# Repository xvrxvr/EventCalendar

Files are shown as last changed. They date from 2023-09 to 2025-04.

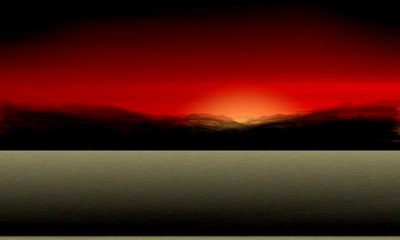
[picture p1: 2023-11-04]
soft/firmware/main/test_bg.jpg

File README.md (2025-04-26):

# EventCalendar
Event Calendar Project

This project is a custom hardware device (with an ESP32 microcontroller, an LCD, a fingerprint sensor, and a bunch of solenoids that are used as control locks for a set of small doors)
Each door closes a separate box with some kind of gift.
The user must solve some kind of puzzle to open the door.

## Project Contents

Directory Contents:

* 3D contains a 3D model for the panel around the LCD
* sch - Schematic. The PCB version is outdated at this point (some schematic changes were made after the PCB was provided). There are also 2 schematics:
  * **ev_cal** - The calendar itself
  * **vboost** - Voltage boost for the solenoids (it is connected instead of L1)
* soft - Software. 6 directories included:
  * expr_quest - Prototype (in Python) for benchmark testing
  * firmware - Firmware (VS Code + IDF plugin)
  * sg - Character generator scripts
  * tst - Hardware test (VS Code + IDF plugin)
  * bloader - OTA loader (OTA is also supported in the main software)
  * ext_logger - External logger client. The external logging system is currently under development. It allows forwarding all internal UART messages to a remote TCP server. This system (with OTA capability) allows creating and debugging new software versions without special software hardware.
* spice - Spice mode for the voltage amplifier

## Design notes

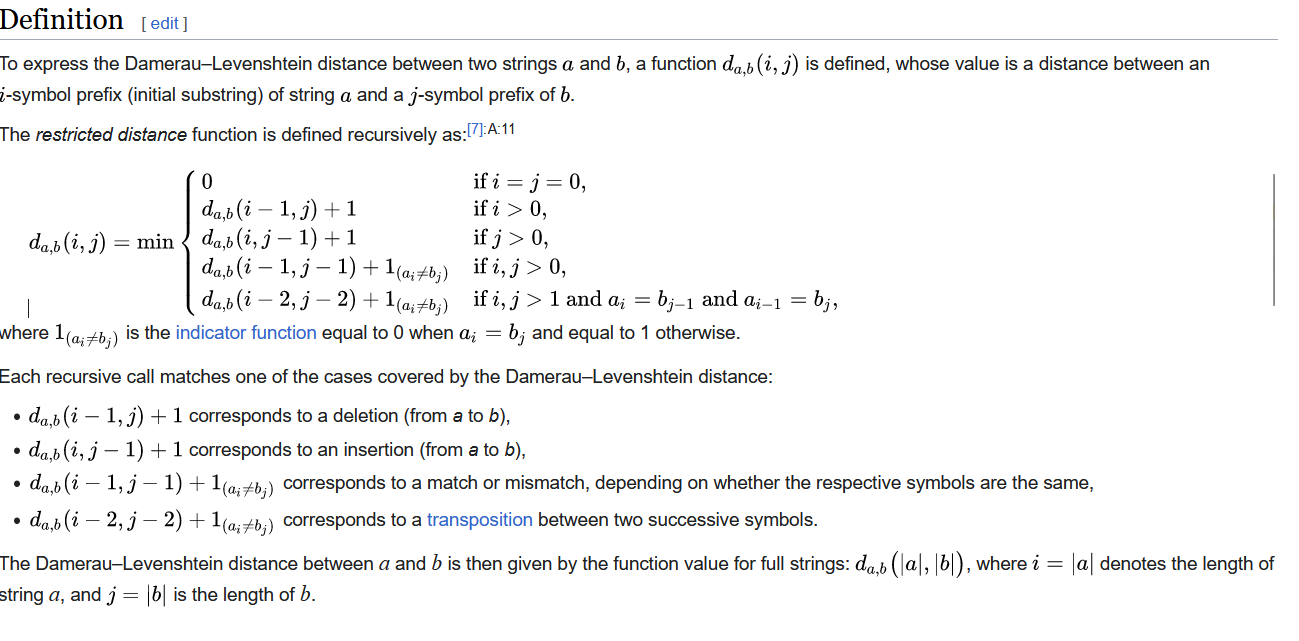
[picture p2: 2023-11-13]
text_draw/DV.png

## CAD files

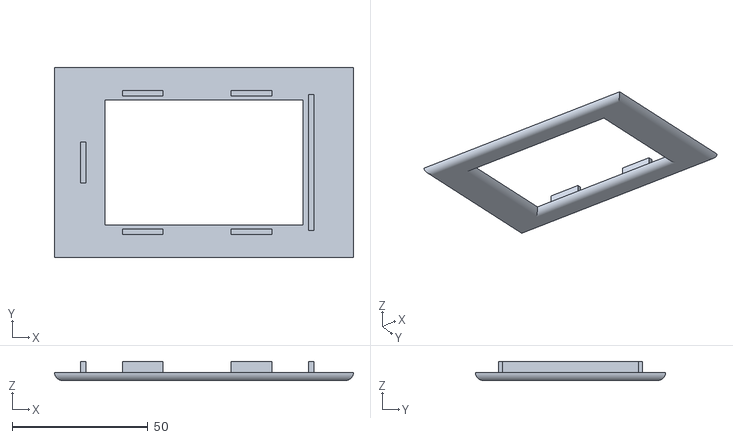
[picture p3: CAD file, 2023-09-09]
3D/lcd-panel-Body.stl
110.0 x 70.0 x 7.00

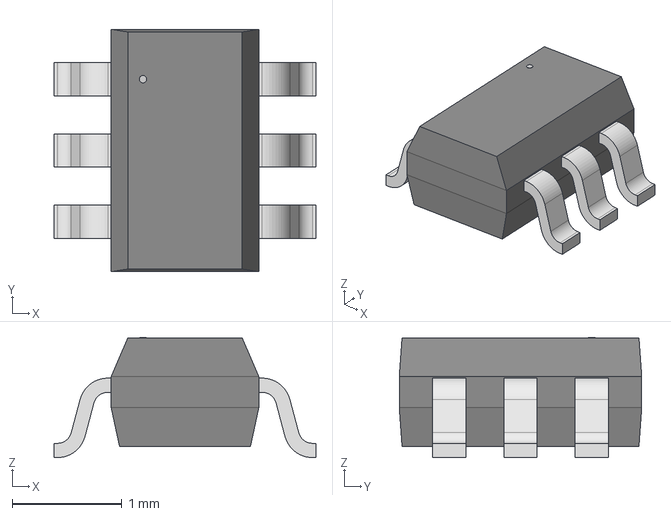
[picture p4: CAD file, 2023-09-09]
sch/ev_cal/KS_6_ADI.step
2.39 x 2.21 x 1.09 mm

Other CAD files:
3D/lcd-panel.FCStd

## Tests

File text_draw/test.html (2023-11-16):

? Run! | Text Visual Appearance setup

Box Model

| Vertical | Horizontal
Margin (0-63):
Padding (0-63):

Other Colors

Default Text color:
Panel color:

Answer Boxes (Selection) Setup

Center text vertically in Box:
Center text horizontally in Box:
Make Boxes equal vertically sized:
Make Boxes equal horizontally sized:

Box Sizing

Corner radius (0-63):
Border (0-63):
Shadow (0-63):

Age

Min: | | Max:

Options

Default char size: | | Input type:
Answer boxes layout:
Fuzzy compare distance (symbols or percent):
Word Wrap:

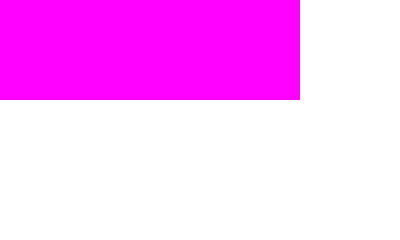
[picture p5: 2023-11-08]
test.png

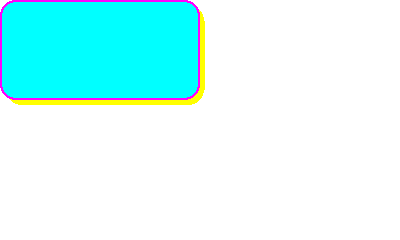
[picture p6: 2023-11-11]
test/test.png

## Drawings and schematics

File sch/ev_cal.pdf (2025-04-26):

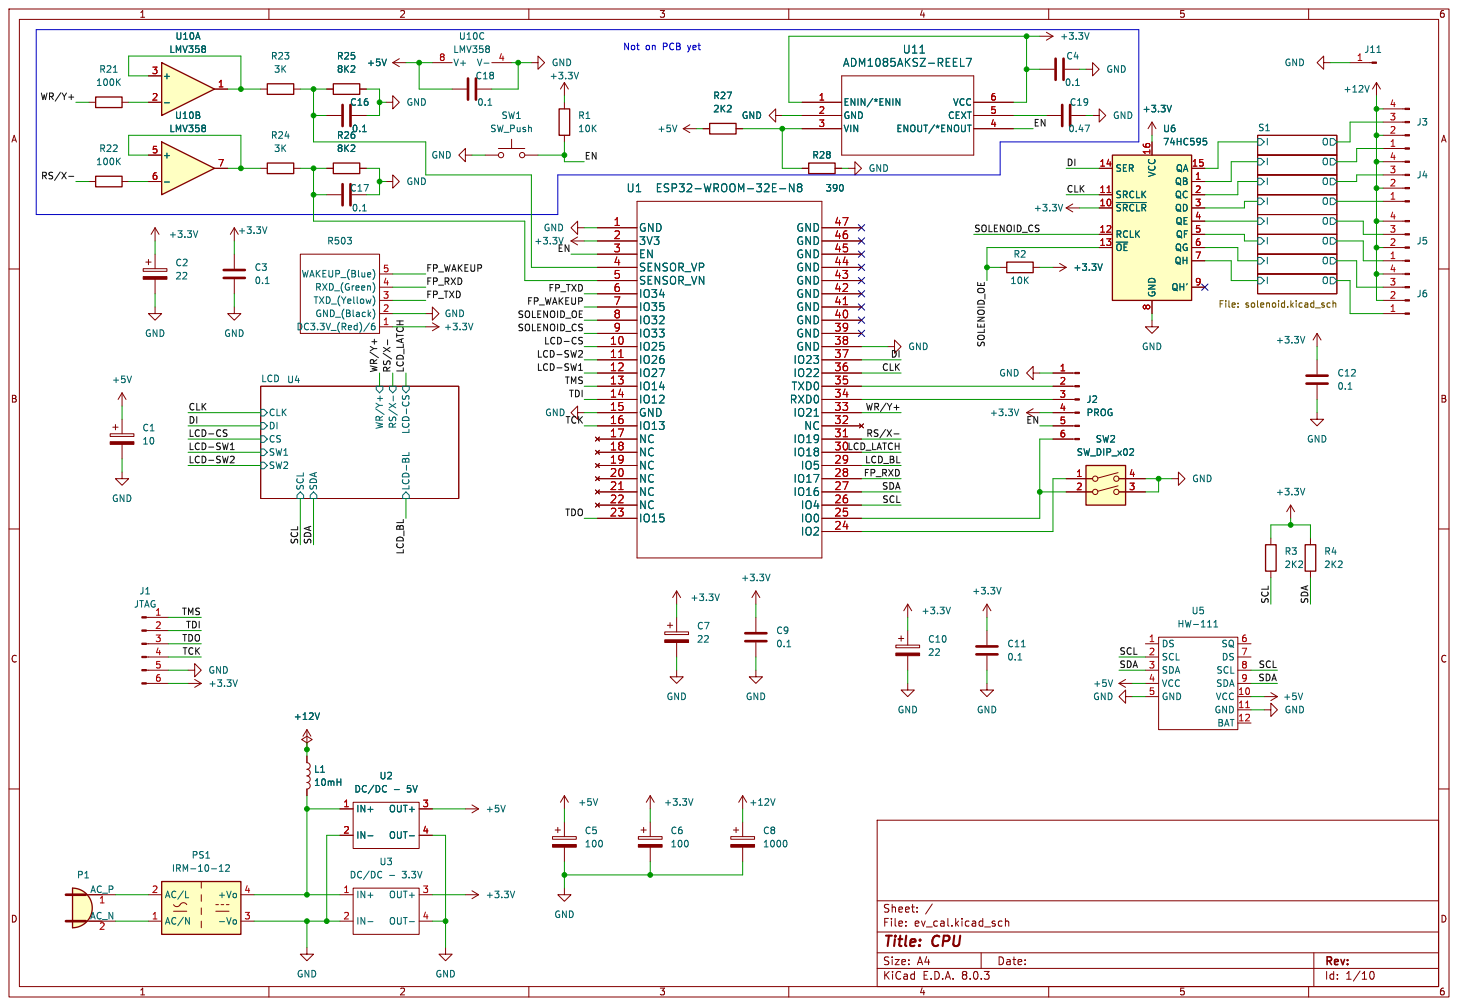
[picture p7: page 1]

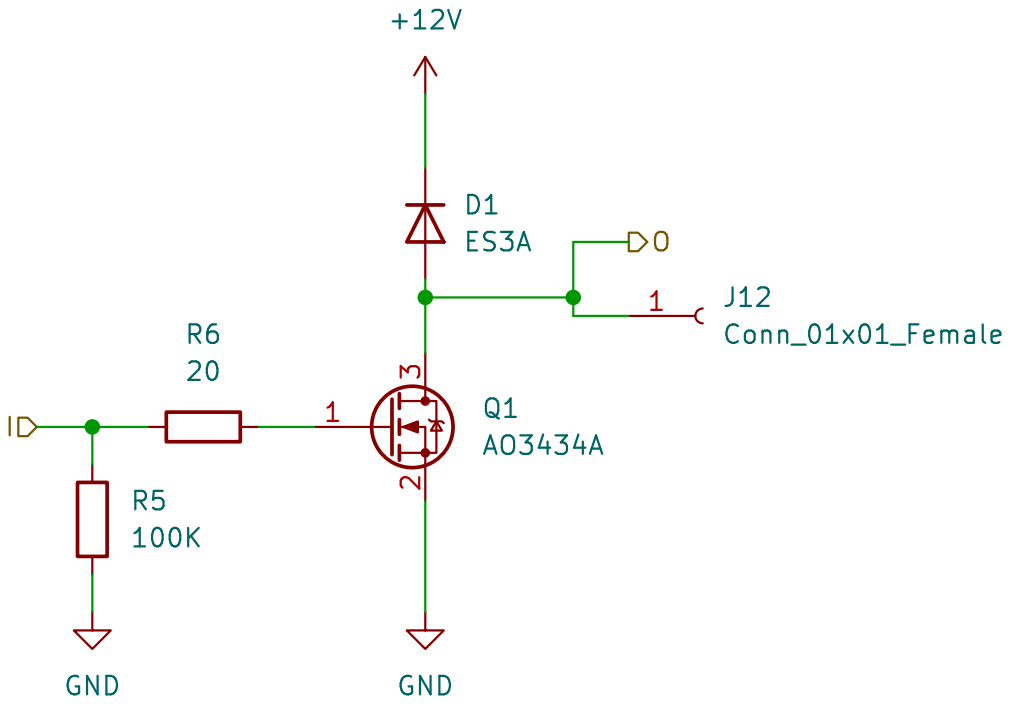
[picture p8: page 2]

Id: 2/10 Title: Solenoid Driver File: solenoid.kicad_sch Sheet: /S1/

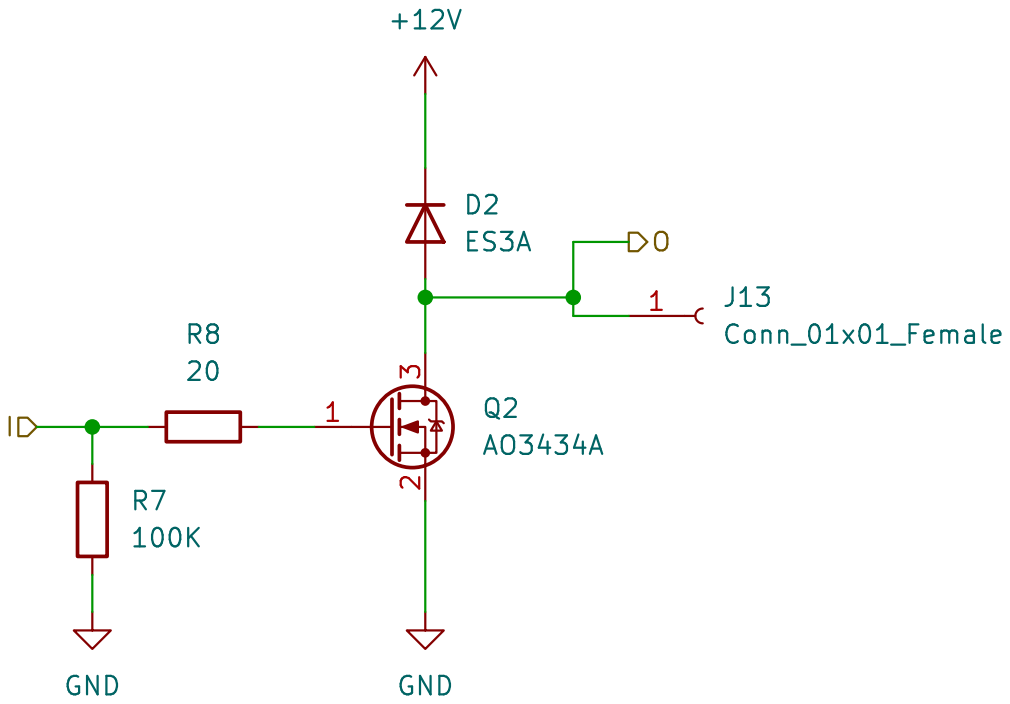
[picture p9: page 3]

Id: 3/10 Title: Solenoid Driver File: solenoid.kicad_sch Sheet: /S2/

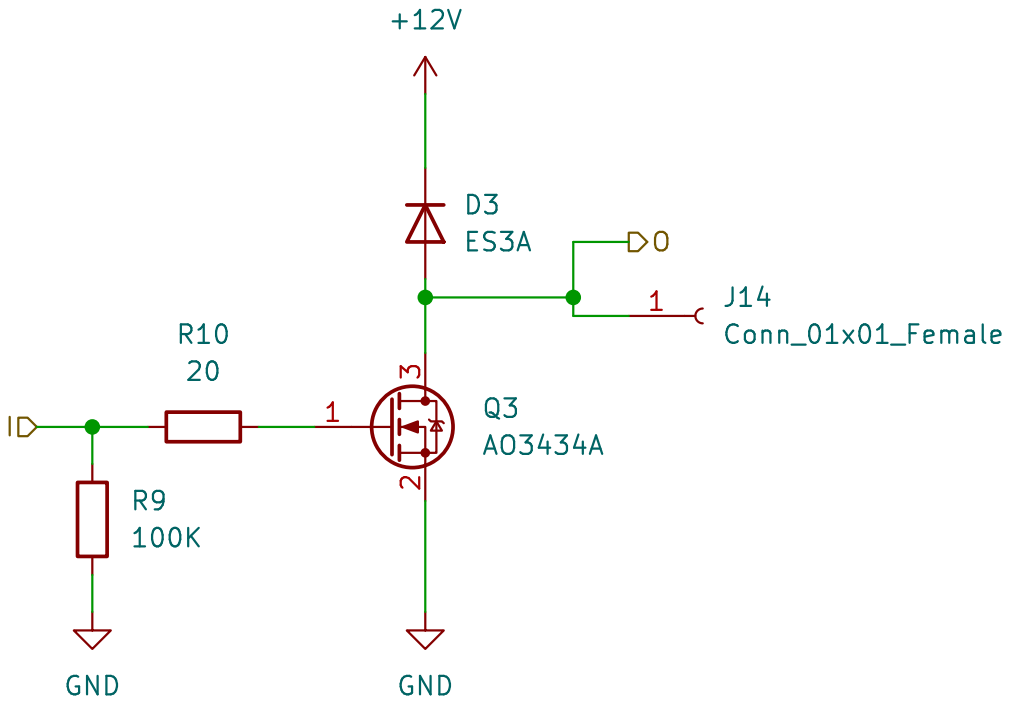
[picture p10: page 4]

Id: 4/10 Title: Solenoid Driver File: solenoid.kicad_sch Sheet: /S3/

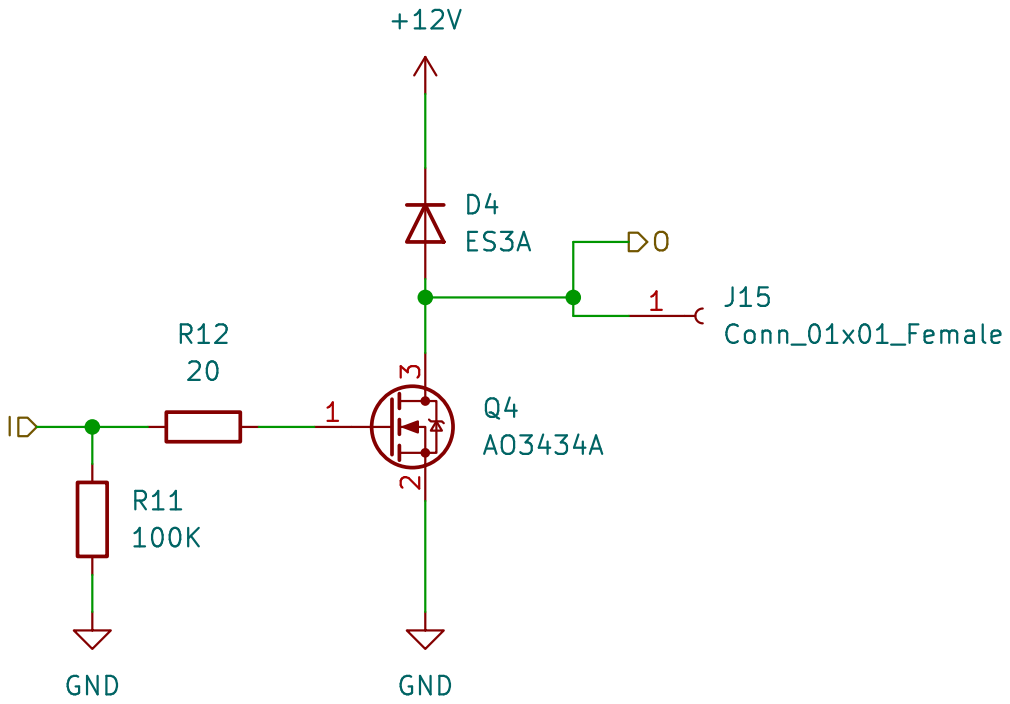
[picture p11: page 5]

Id: 5/10 Title: Solenoid Driver File: solenoid.kicad_sch Sheet: /S4/

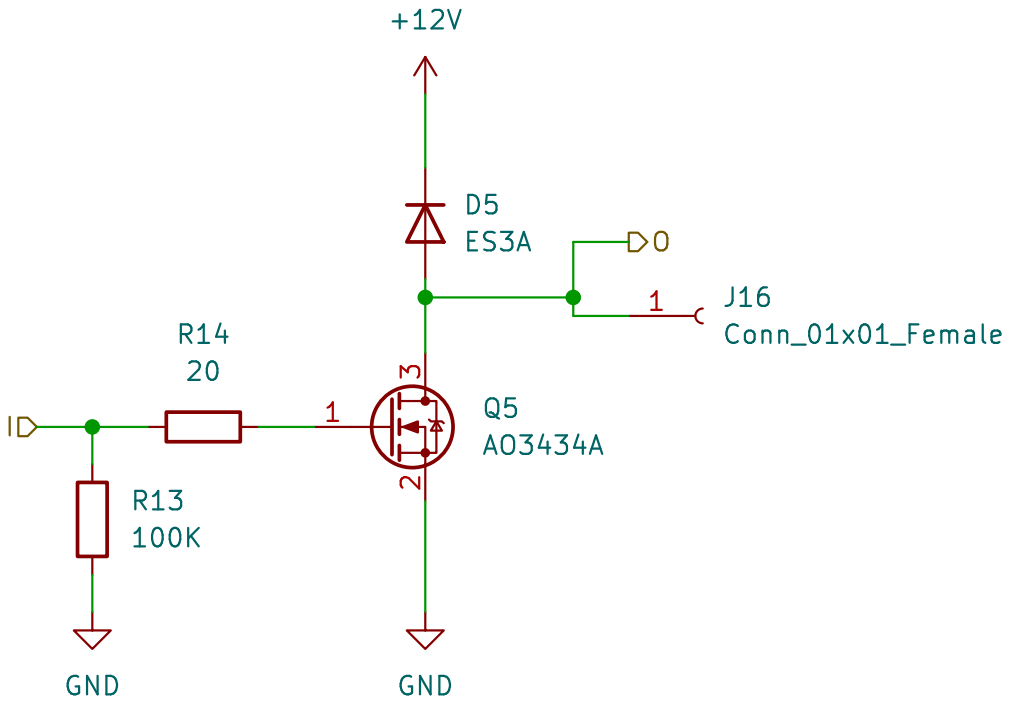
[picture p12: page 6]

Id: 6/10 Title: Solenoid Driver File: solenoid.kicad_sch Sheet: /S5/

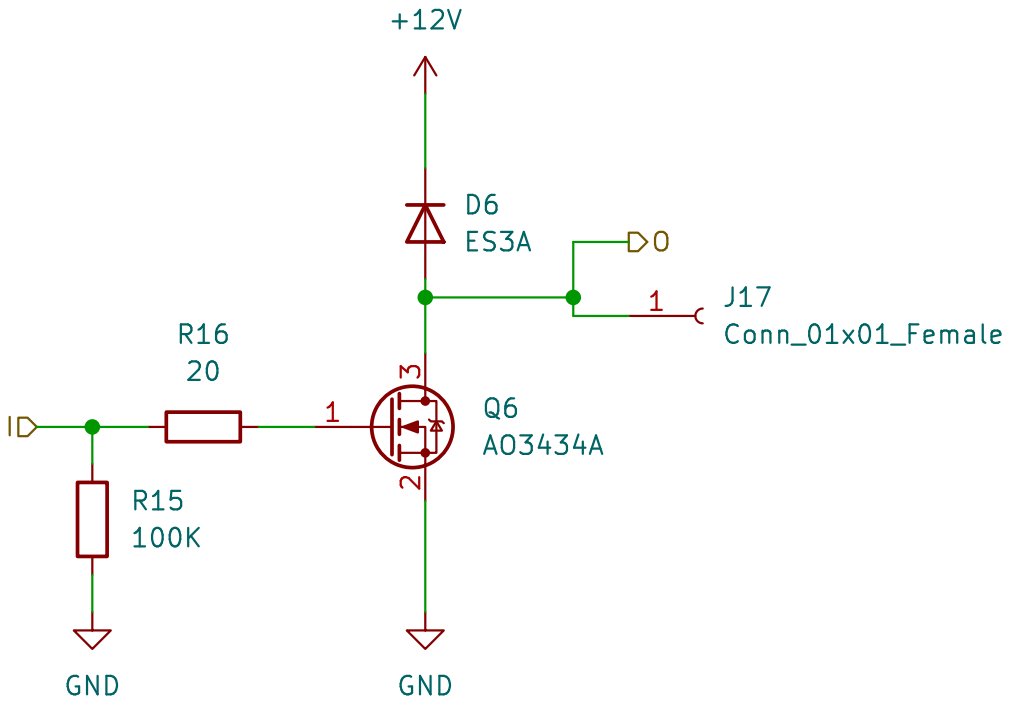
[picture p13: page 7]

Id: 7/10 Title: Solenoid Driver File: solenoid.kicad_sch Sheet: /S6/

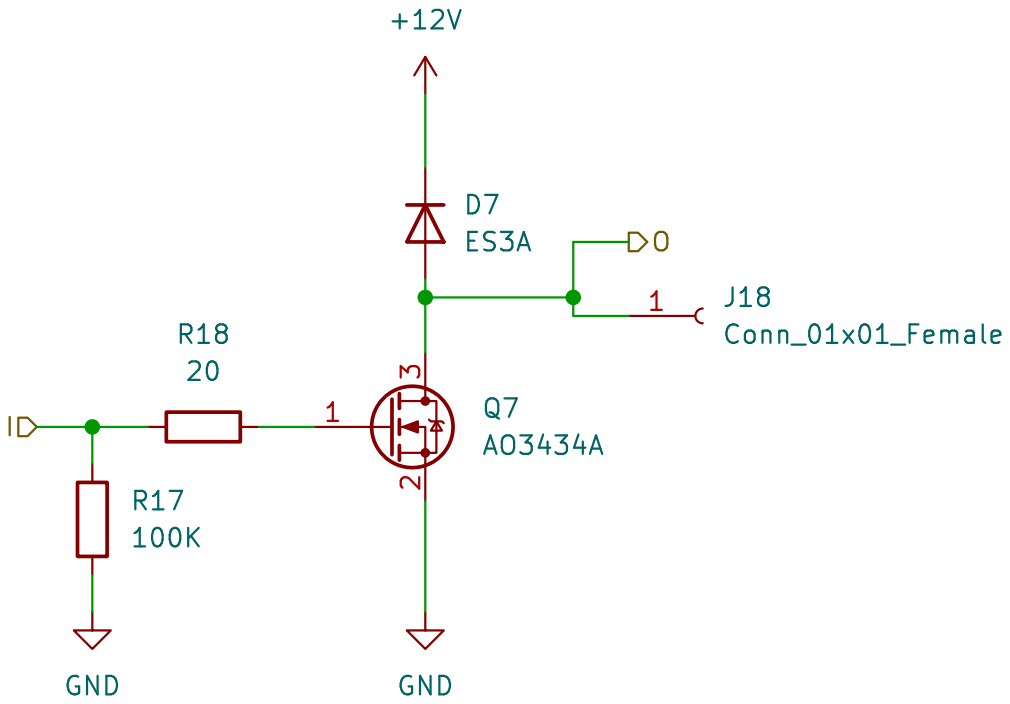
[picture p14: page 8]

Id: 8/10 Title: Solenoid Driver File: solenoid.kicad_sch Sheet: /S7/

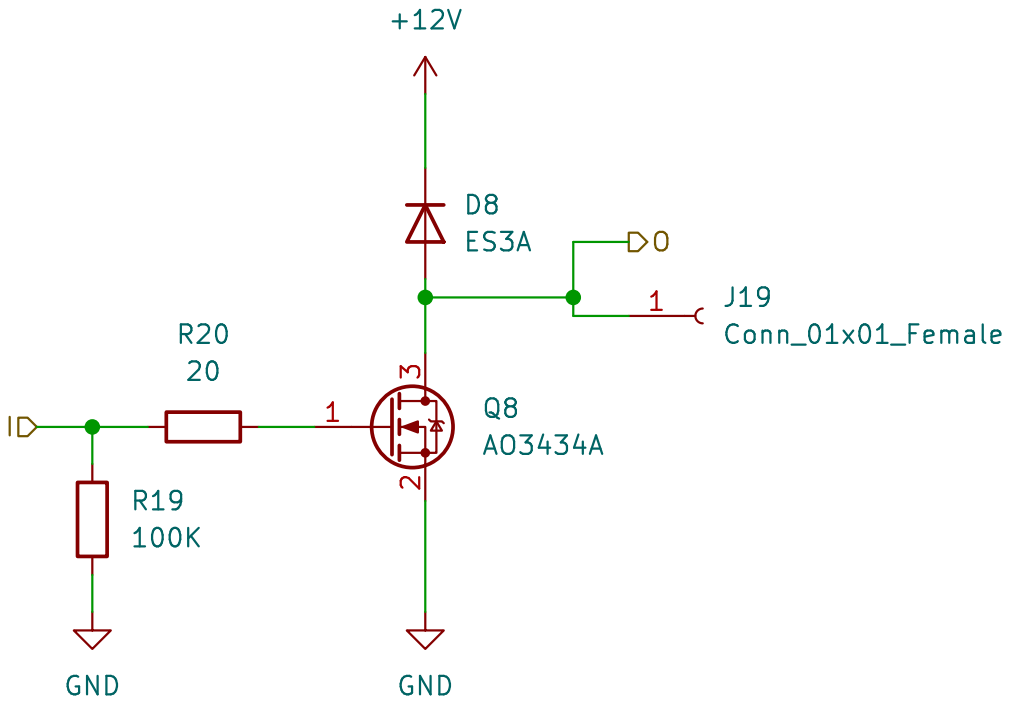
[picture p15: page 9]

Id: 9/10 Title: Solenoid Driver File: solenoid.kicad_sch Sheet: /S8/

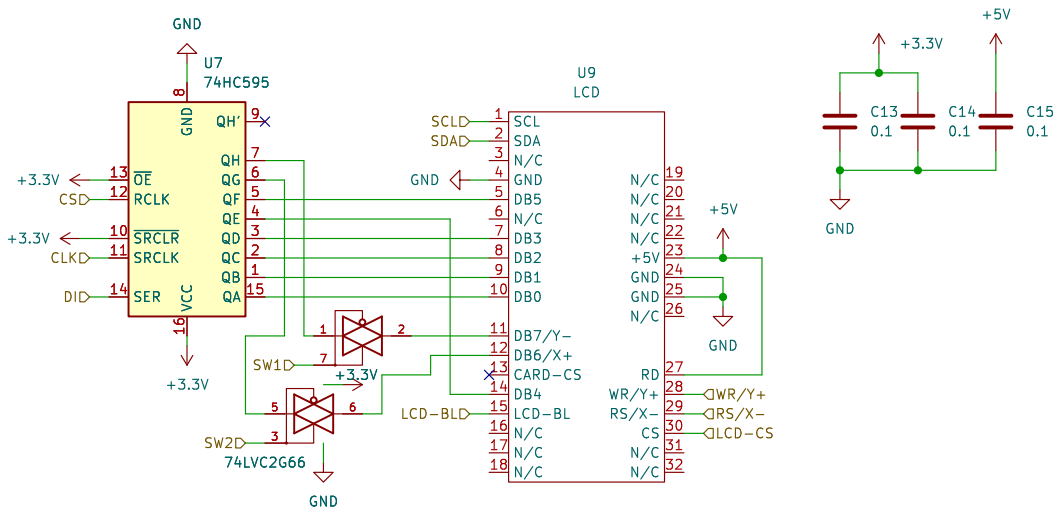
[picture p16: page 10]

File: lcd.kicad_sch Sheet: /LCD/
Id: 10/10 Title: LCD

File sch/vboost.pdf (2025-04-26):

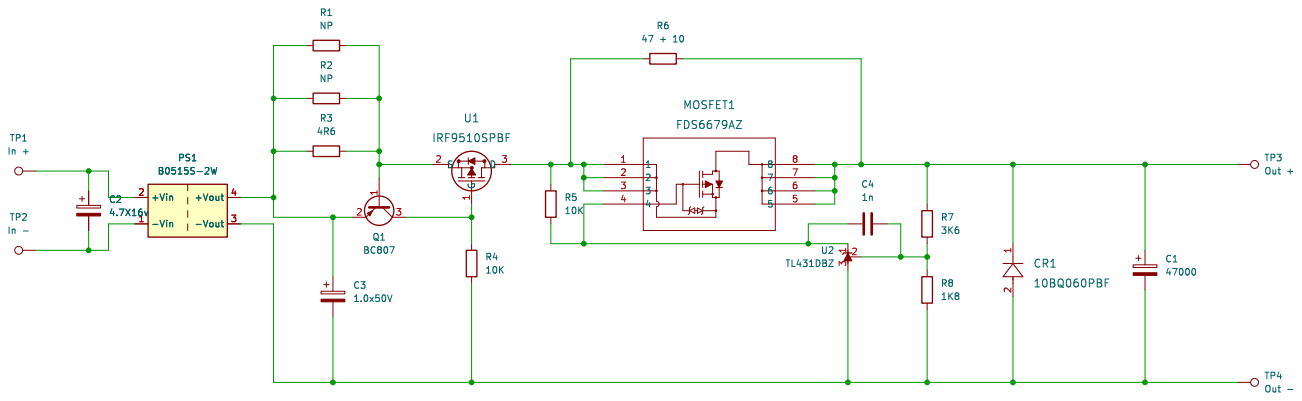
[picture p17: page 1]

Id: 1/1 Title: File: vboost.kicad_sch Sheet: /

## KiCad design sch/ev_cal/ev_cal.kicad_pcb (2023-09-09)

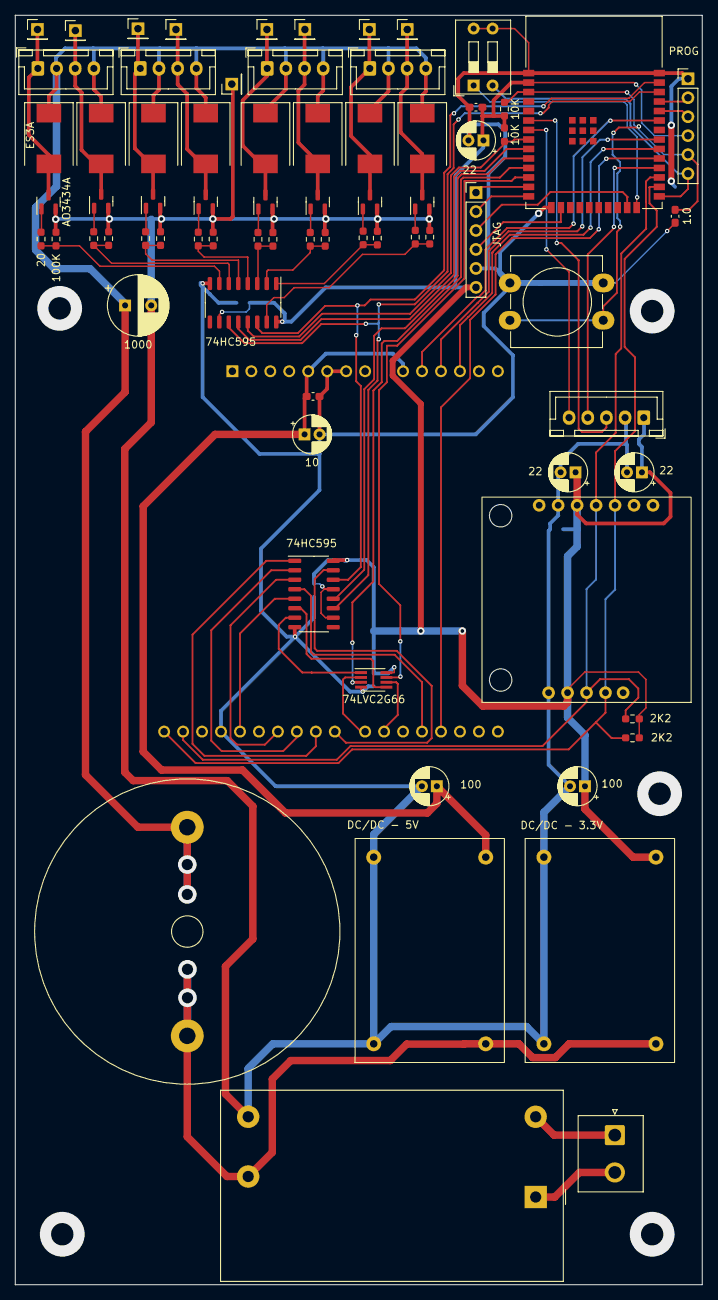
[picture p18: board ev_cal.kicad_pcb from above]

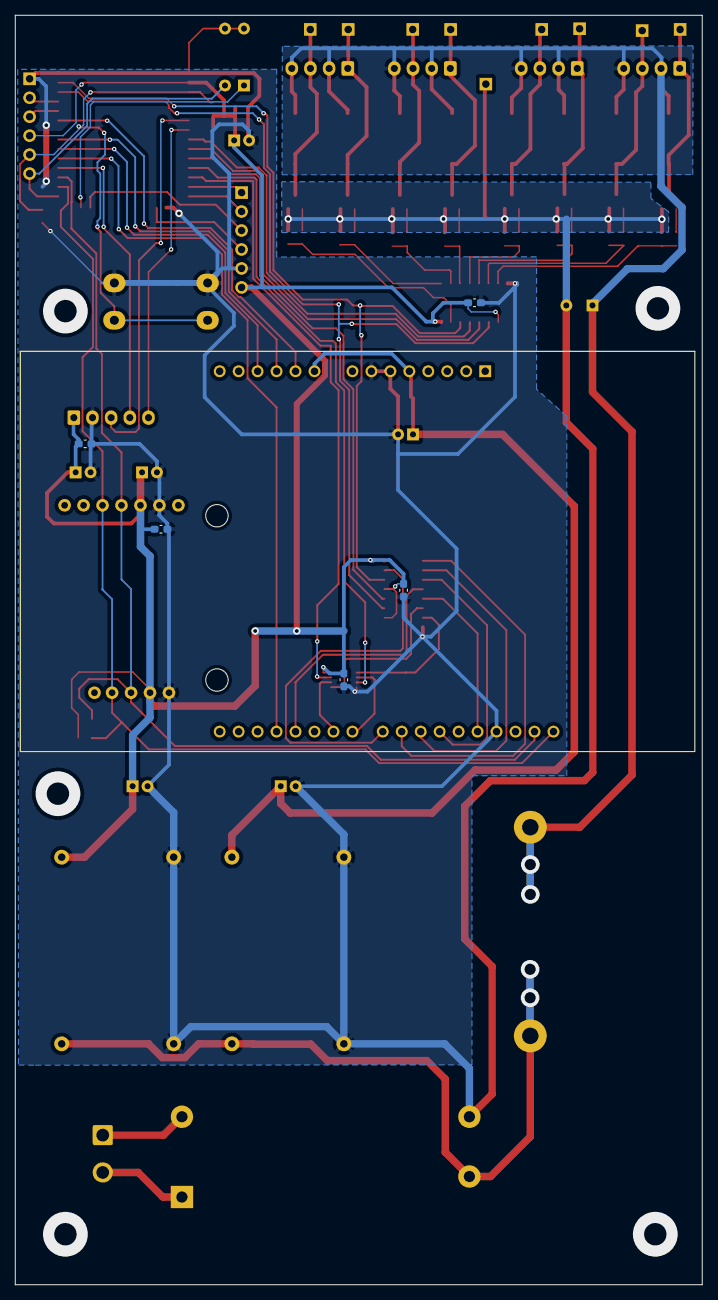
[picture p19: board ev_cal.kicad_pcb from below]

Board: 2 copper layers, 92.0 x 170.0 mm, 80 parts (6 on the bottom side), 66 nets.

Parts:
C1: 10; CP_Radial_D5.0mm_P2.00mm
C2, C7, C10: 22; CP_Radial_D5.0mm_P2.00mm
C3, C9, C11, C12, C13, C14, C15: 0.1; C_0603_1608Metric_Pad1.08x0.95mm_HandSolder
C4: 1.0; C_0603_1608Metric_Pad1.08x0.95mm_HandSolder
C5, C6: 100; CP_Radial_D5.0mm_P2.00mm
C8: 1000; CP_Radial_D8.0mm_P3.50mm
D1, D2, D3, D4, D5, D6, D7, D8: ES3A; D_SMC
J1: JTAG; PinHeader_1x06_P2.54mm_Vertical
J2: PROG; PinHeader_1x06_P2.54mm_Vertical
J3, J4, J5, J6: Conn_01x04_Male; JST_XH_B4B-XH-A_1x04_P2.50mm_Vertical
J11: Conn_01x01_Male; PinHeader_1x01_P2.54mm_Vertical
J12, J13, J14, J15, J16, J17, J18, J19: Conn_01x01_Female; PinHeader_1x01_P2.54mm_Vertical
L1: 10mH; L_Radial_D40.6mm_P27.94mm_Vishay_IHB-4
P1: Conn_WallPlug; JST_NV_B02P-NV_1x02_P5.00mm_Vertical
PS1: IRM-10-12; Converter_ACDC_MeanWell_IRM-10-xx_THT
Q1, Q2, Q3, Q4, Q5, Q6, Q7, Q8: AO3434A; SOT-23
R1, R2: 10K; R_0603_1608Metric_Pad0.98x0.95mm_HandSolder
R3, R4: 2K2; R_0603_1608Metric_Pad0.98x0.95mm_HandSolder
R5, R7, R9, R11, R13, R15, R17, R19: 100K; R_0603_1608Metric_Pad0.98x0.95mm_HandSolder
R6, R8, R10, R12, R14, R16, R18, R20: 20; R_0603_1608Metric_Pad0.98x0.95mm_HandSolder
SW1: SW_Push; SW_PUSH-12mm_Wuerth-430476085716
SW2: SW_DIP_x02; SW_DIP_SPSTx02_Slide_9.78x7.26mm_W7.62mm_P2.54mm
U1: ESP32-WROOM-32E-N8
U2: DC/DC - 5V; DD_DC
U3: DC/DC - 3.3V; DD_DC
U4: R503; JST_XH_B5B-XH-A_1x05_P2.50mm_Vertical
U5: HW-111
U6, U7: 74HC595; SO-16_3.9x9.9mm_P1.27mm
U8: 74LVC2G66; SSOP-8_2.95x2.8mm_P0.65mm
U9: LCD

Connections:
+3.3V: C2.1, C3.1, C6.1, C7.1, C9.1, C10.1, C11.1, C12.1, C13.1, C14.1, J1.6, J2.4, R1.1, R2.2, R3.1, R4.1, U1.2 (3V3), U3.3 (OUT+), U4.1 (DC3.3V_(Red)/6), U5.4 (VCC), U5.10 (VCC), U6.10 (~SRCLR), U6.16 (VCC), U7.10 (~SRCLR), U7.13 (~OE), U7.16 (VCC), U8.8 (+3.3V)
+5V: C1.1, C5.1, C15.1, U2.3 (OUT+), U9.23 (+5V), U9.27 (RD)
+12V: C8.1, D1.1 (K), D2.1 (K), D3.1 (K), D4.1 (K), D5.1 (K), D6.1 (K), D7.1 (K), D8.1 (K), J3.2, J3.4, J4.2, J4.4, J5.2, J5.4, J6.2, J6.4, L1.1
/CLK: U1.36 (IO22), U6.11 (SRCLK), U7.11 (SRCLK)
/DI: U1.37 (IO23), U6.14 (SER), U7.14 (SER)
/EN: C4.1, J2.5, R1.2, SW1.2, U1.3 (EN)
/FP_RXD: U1.28 (IO17), U4.4 (RXD_(Green))
/FP_TXD: U1.6 (IO34), U4.3 (TXD_(Yellow))
/FP_WAKEUP: U1.7 (IO35), U4.5 (WAKEUP_(Blue))
/LCD-CS: U1.10 (IO25), U7.12 (RCLK)
/LCD-SW1: U1.12 (IO27), U8.7
/LCD-SW2: U1.11 (IO26), U8.3
/LCD_BL: U1.29 (IO5), U9.15 (LCD-BL)
/LCD_LATCH: U1.30 (IO18), U9.30 (CS)
/RS/X-: U1.31 (IO19), U9.29 (RS/X-)
/S1/I: R5.1, R6.1, U6.15 (QA)
/S1/O: D1.2 (A), J3.3, J12.1, Q1.3 (D)
/S2/I: R7.1, R8.1, U6.1 (QB)
/S2/O: D2.2 (A), J3.1, J13.1, Q2.3 (D)
/S3/I: R9.1, R10.1, U6.2 (QC)
/S3/O: D3.2 (A), J4.3, J14.1, Q3.3 (D)
/S4/I: R11.1, R12.1, U6.3 (QD)
/S4/O: D4.2 (A), J4.1, J15.1, Q4.3 (D)
/S5/I: R13.1, R14.1, U6.4 (QE)
/S5/O: D5.2 (A), J5.3, J16.1, Q5.3 (D)
/S6/I: R15.1, R16.1, U6.5 (QF)
/S6/O: D6.2 (A), J5.1, J17.1, Q6.3 (D)
/S7/I: R17.1, R18.1, U6.6 (QG)
/S7/O: D7.2 (A), J6.3, J18.1, Q7.3 (D)
/S8/I: R19.1, R20.1, U6.7 (QH)
/S8/O: D8.2 (A), J6.1, J19.1, Q8.3 (D)
/SCL: R3.2, U1.26 (IO4), U5.2 (SCL), U5.8 (SCL), U9.1 (SCL)
/SDA: R4.2, U1.27 (IO16), U5.3 (SDA), U5.9 (SDA), U9.2 (SDA)
/SOLENOID_CS: U1.9 (IO33), U6.12 (RCLK)
/SOLENOID_OE: R2.1, U1.8 (IO32), U6.13 (~OE)
/TCK: J1.4, U1.16 (IO13)
/TDI: J1.2, U1.14 (IO12)
/TDO: J1.3, U1.23 (IO15)
/TMS: J1.1, U1.13 (IO14)
/WR/Y+: U1.33 (IO21), U9.28 (WR/Y+)
GND: C1.2, C2.2, C3.2, C4.2, C5.2, C6.2, C7.2, C8.2, C9.2, C10.2, C11.2, C12.2, C13.2, C14.2, C15.2, J1.5, J2.1, J11.1, PS1.3 (-Vo), Q1.2 (S), Q2.2 (S), Q3.2 (S), Q4.2 (S), Q5.2 (S), Q6.2 (S), Q7.2 (S), Q8.2 (S), R5.2, R7.2, R9.2, R11.2, R13.2, R15.2, R17.2, R19.2, SW1.1, SW2.3, SW2.4, U1.1 (GND), U1.15 (GND), U1.38 (GND), U2.2 (IN-), U2.4 (OUT-), U3.2 (IN-), U3.4 (OUT-), U4.2 (GND_(Black)), U5.5 (GND), U5.11 (GND), U6.8 (GND), U7.8 (GND), U8.4 (GND), U9.4 (GND), U9.24 (GND), U9.25 (GND)
unnamed: J2.2, U1.35 (TXD0)
unnamed: J2.3, U1.34 (RXD0)
unnamed: J2.6, SW2.2, U1.25 (IO0)
unnamed: L1.2, PS1.4 (+Vo), U2.1 (IN+), U3.1 (IN+)
unnamed: P1.1 (AC_P), PS1.2 (AC/L)
unnamed: P1.2 (AC_N), PS1.1 (AC/N)
unnamed: Q1.1 (G), R6.2
unnamed: Q2.1 (G), R8.2
unnamed: Q3.1 (G), R10.2
unnamed: Q4.1 (G), R12.2
unnamed: Q5.1 (G), R14.2
unnamed: Q6.1 (G), R16.2
unnamed: Q7.1 (G), R18.2
unnamed: Q8.1 (G), R20.2
unnamed: SW2.1, U1.24 (IO2)
unnamed: U7.1 (QB), U9.9 (DB1)
unnamed: U7.2 (QC), U9.8 (DB2)
unnamed: U7.3 (QD), U9.7 (DB3)
unnamed: U7.4 (QE), U9.14 (DB4)
unnamed: U7.5 (QF), U9.5 (DB5)
unnamed: U7.6 (QG), U8.5
unnamed: U7.7 (QH), U8.1
unnamed: U7.15 (QA), U9.10 (DB0)
unnamed: U8.2, U9.11 (DB7/Y-)
unnamed: U8.6, U9.12 (DB6/X+)

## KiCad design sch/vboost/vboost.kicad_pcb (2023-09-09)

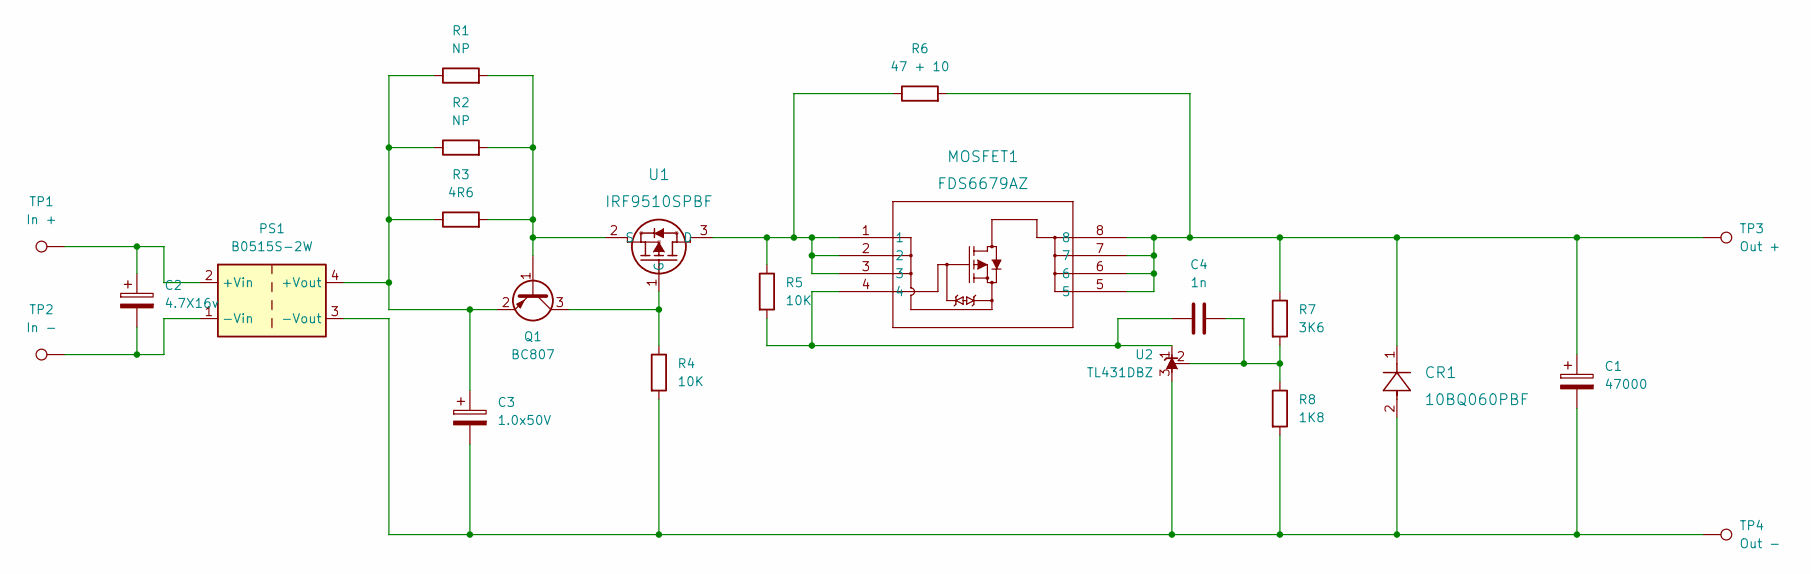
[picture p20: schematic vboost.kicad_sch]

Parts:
C1: 47000; CP_Radial_D35.0mm_P10.00mm_SnapIn
C2: 4.7X16v; CP_Radial_D5.0mm_P2.00mm
C3: 1.0x50V; CP_Radial_D5.0mm_P2.00mm
C4: 1n; C_0805_2012Metric_Pad1.18x1.45mm_HandSolder
CR1: 10BQ060PBF; DIODE_SMB_VIS-M
MOSFET1: FDS6679AZ; SOIC8_751EB_ONS-M
PS1: B0515S-2W
Q1: BC807; SOT-23
R1, R2: NP; R_0805_2012Metric_Pad1.20x1.40mm_HandSolder
R3: 4R6; R_0805_2012Metric_Pad1.20x1.40mm_HandSolder
R4, R5: 10K; R_0805_2012Metric_Pad1.20x1.40mm_HandSolder
R6: 47 + 10; R2
R7: 3K6; R_0805_2012Metric_Pad1.20x1.40mm_HandSolder
R8: 1K8; R_0805_2012Metric_Pad1.20x1.40mm_HandSolder
TP1: In +; TP1
TP2: In -; TP1
TP3: Out +; TP1
TP4: Out -; TP1
U1: IRF9510SPBF; D2PAK_VIS-M
U2: TL431DBZ; SOT-23

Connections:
unnamed: C1.1, CR1.1, MOSFET1.5, MOSFET1.6, MOSFET1.7, MOSFET1.8, R6.2, R7.1, TP3.1
unnamed: C1.2, C3.2, CR1.2, PS1.3 (-Vout), R4.2, R8.2, TP4.1, U2.3 (A)
unnamed: C2.1, PS1.2 (+Vin), TP1.1
unnamed: C2.2, PS1.1 (-Vin), TP2.1
unnamed: C3.1, PS1.4 (+Vout), Q1.2 (E), R1.1, R2.1, R3.1
unnamed: C4.1, MOSFET1.4, R5.2, U2.1 (K)
unnamed: C4.2, R7.2, R8.1, U2.2 (REF)
unnamed: MOSFET1.1, MOSFET1.2, MOSFET1.3, R5.1, R6.1, U1.3 (D)
unnamed: Q1.1 (B), R1.2, R2.2, R3.2, U1.2 (S)
unnamed: Q1.3 (C), R4.1, U1.1 (G)

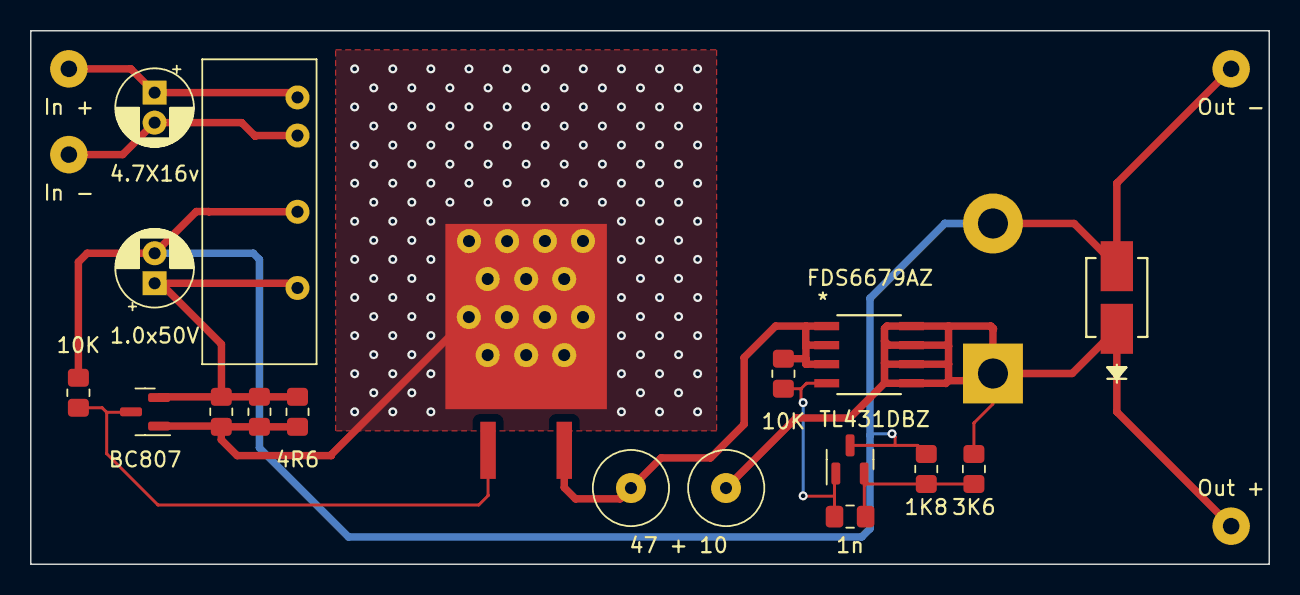
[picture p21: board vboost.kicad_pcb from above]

Board: 2 copper layers, 82.5 x 35.6 mm, 22 parts (1 on the bottom side), 10 nets.

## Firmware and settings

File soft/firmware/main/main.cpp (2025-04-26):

#include "common.h"

#include "hadrware.h"
#include "setup_data.h"
#include "wifi_module.h"
#include "activity.h"
#include "interactive.h"
#include "challenge_list.h"
#include "log_control.h"

void start_http_servers();

extern "C" void app_main(void)
{
    hw_init();
    init_or_load_setup();
    wifi_init();
    start_http_servers();
    
    if (TouchConfig().touched()) process_initial_log_setup();

    Activity::start();

    for(;;) {Interactive::entry(); vTaskDelay(100);}
}

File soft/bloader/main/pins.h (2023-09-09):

#pragma once

#define PIN_NUM_CLK     GPIO_NUM_22
#define PIN_NUM_MOSI    GPIO_NUM_23
#define PIN_NUM_CS_SOL  GPIO_NUM_33
#define PIN_NUM_CS_LCD  GPIO_NUM_25

#define PIN_NUM_OE_SOL  GPIO_NUM_32

#define PIN_NUM_LCD_CS  GPIO_NUM_18
#define PIN_NUM_LCD_BL   GPIO_NUM_5
#define PIN_NUM_LCD_SW1 GPIO_NUM_27
#define PIN_NUM_LCD_SW2 GPIO_NUM_26
#define PIN_NUM_LCD_WR  GPIO_NUM_21
#define PIN_NUM_LCD_RS  GPIO_NUM_19

/*
    CS      - 18
    BL      - 5           LCD    TouchX  TouchY  TouchSence     TouchSence/Alt    Idle
    DB7/Y- (SW1) - 27    1/DB7     0      1/0       1/0             0             1/1
    DB6/X+ (SW2) - 26    1/DB6    1/1      0         0             1/0            1/1
    WR/Y+   - 21          WR      ADC      1         0           PullUP/Sence      1       -> 36 (SENSOR_VP)
    RS/X-   - 19          RS       0      ADC     PullUP/Sence      0              1       -> 39 (SENSOR_VN)
*/


#define PIN_NUM_FP_TXD  GPIO_NUM_34
#define PIN_NUM_FP_RXD  GPIO_NUM_17
#define PIN_NUM_FP_WAKEUP GPIO_NUM_35

#define PIN_NUM_I2C_SDA     GPIO_NUM_16
#define PIN_NUM_I2C_SCL      GPIO_NUM_4

#define PIN_NUM_DIPSW_BOOT   GPIO_NUM_0
#define PIN_NUM_DIPSW_AUX    GPIO_NUM_2

#define ADC_Y_PLUS  ADC_CHANNEL_0
#define ADC_X_MINUS ADC_CHANNEL_3

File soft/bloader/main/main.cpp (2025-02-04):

#include "common.h"

#include "hadrware.h"
#include "setup_data.h"
#include "wifi_module.h"
#include "tftp/include/tftp_ota_server.h"

extern "C" void app_main(void)
{
    hw_init();
    init_or_load_setup();
    wifi_init();

    lcd.gotoxy(LCD_AP_ROW);
    lcd.print("SSID: " MASTER_WIFI_SSID "\nPSWD: " MASTER_WIFI_PASSWD "\nIP  : 192.168.4.1");

    TftpOtaServer srv;
    if (srv.start())
    {
        lcd.error("Can't start TFTP server.\nRestart please.");
        for(;;);
    }
    lcd.status("Waiting for update");
    for(;;) srv.run();
}


void LCD::print(const char* msg) // \n also handled
{
    while(msg && msg_y < 15)
    {
        int x = msg_x*16;
        char* endp = strchr(msg, '\n');
        int len = endp ? endp-msg : strlen(msg);
        if (msg_x + len <= 25) // Size is 2
        {
            text2(msg, x, msg_y*32, len);
            msg_x += len;
        }
        else // size is 1
        {
            if (msg_x*2 + len > 50) len = 50-msg_x*2;
            text(msg, x, msg_y*32, len);
            msg_x += (len+1) >> 1;
        }
        if (msg_x < 25) WRect(msg_x*16, msg_y*32, (25-msg_x)*16, 32, 0);
        if (!endp) break;
        msg = endp+1;
        msg_x=0; 
        ++msg_y;
    }
}

// Progress indicator
// 400x48, block 4x4 (3x3 + 1 px marging) => 100x12
// PI row - 11*16 = 176 (44 block row). Total - 100x16 = 1600. 
// 4M download => 2*1310 bytes/block
#define BYTES_PER_BLOCK (4*1024*1024/(100*(240-LCD_MSG_PI*32)/4)+1)

void LCD::pi_inc_loaded(size_t inc)
{
    int cur_block = loaded / BYTES_PER_BLOCK;
    loaded += inc;
    int next_block = (loaded + BYTES_PER_BLOCK - 1) / BYTES_PER_BLOCK;

    for(int i=cur_block; i<next_block; ++i)
    {
        int col = i % 100;
        int row = i / 100;
        WRect(col*4, row*4+ LCD_MSG_PI*32, 3, 3, rgb(0, 0xFF, 0));
    }
}

void reboot()
{
    esp_task_wdt_config_t twdt_config = {
        .timeout_ms = 5000,
        .idle_core_mask = (1 << portNUM_PROCESSORS) - 1,    // Bitmask of all cores
        .trigger_panic = true
    };
    ESP_ERROR_CHECK(esp_task_wdt_init(&twdt_config));
    esp_task_wdt_add(NULL);
}

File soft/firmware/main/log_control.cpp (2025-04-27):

#include "common.h"
#include "web_gadgets.h"
#include "setup_data.h"

#include <cJSON.h>
#include "lwip/sockets.h"
#include "esp_core_dump.h"

#include "log_control.h"

#include <esp_core_dump.h>

static const char* TAG = "LogMgr";

static vprintf_like_t prev_logger;
static bool remote_logger_active = false;
static uint32_t data_sent = 0;
static uint32_t max_remote_buffer = 0;
static int log_spliced = 0;

static TaskHandle_t log_task_handle;
static SemaphoreHandle_t log_sema;
static Prn log_bufs[2];
static int log_buf_idx=0;

static bool locked = true; // Limit max Prn buffer size to 1K

// JSON format (object):
// {
//    IP: '192.168.0.100',
//    UART: true,
//    Remote: true,
//    DefLL: 'Debug',
//    SoftLim: true,
//    MemLim: 1,
//    Locked: true,
//    Custom: [
//      {tag: 'Tag1', level:'Error'},
//      {tag: 'Tag2', level:'None'},
//      {tag: 'Tag3', level:'Verbose'}
//    ]
// }

static constexpr const char* log_file_name = "/data/logsetup.json";

static constexpr esp_log_level_t str2ll(const char* log_level)
{
    switch(upcase(log_level[0]))
    {
        case 'N': return ESP_LOG_NONE;   // None
        case 'E': return ESP_LOG_ERROR;  // Error
        case 'W': return ESP_LOG_WARN;   // Warning
        case 'I': return ESP_LOG_INFO;   // Info
        case 'D': return ESP_LOG_DEBUG;  // Debug
        case 'V': return ESP_LOG_VERBOSE;// Verbose
        default: return ESP_LOG_NONE;
    }
}

static constexpr const char* ll2str(esp_log_level_t ll)
{
    static constexpr const char* msg[] = {"None", "Error", "Warning", "Info", "Debug", "Verbose"};
    return msg[ll];
}

class LogLock {
public:
    LogLock() {xSemaphoreTake(log_sema, portMAX_DELAY);}
    ~LogLock() {xSemaphoreGive(log_sema);}
};
#define LOCK LogLock _ll

#define GET(nm, tp) obj_item = cJSON_GetObjectItem(J, nm); \
    if (!obj_item) \
    { \
        ESP_LOGE(TAG, "Invalid JSON - Root value \"" nm "\" not found"); \
        return; \
    } \
    if (!cJSON_Is##tp(obj_item)) \
    { \
        ESP_LOGE(TAG, "Invalid JSON - Root value \"" nm "\" not an " #tp); \
        return; \
    }

#define GET_B(var, nm) GET(nm, Bool) bool var = cJSON_IsTrue(obj_item)
#define GET_S(var, nm) GET(nm, String) const char* var = cJSON_GetStringValue(obj_item)
#define GET_I(var, nm) GET(nm, Number) int var = obj_item->valueint

inline uint32_t prn_buf_size()
{
    uint32_t size = global_setup.log_memsize_limit*256;
    return (locked && size > SC_LogStartLim) ? SC_LogStartLim : size;
}

static void process_defaults_level()
{
    esp_log_level_set("*", esp_log_level_t(global_setup.log_setup_options&LSO_DefLogLevelMask));
}

// Process setup for Log Level (from WEB and initial one)
static void process_custom_levels(cJSON* config)
{
    cJSON* J;
    cJSON* obj_item;
    esp_log_level_t logl = esp_log_level_t(global_setup.log_setup_options&LSO_DefLogLevelMask);

    process_defaults_level();
    if (!config)
    {
        ESP_LOGE(TAG, "Invalid Custom Setup JSON - Not found");
        return;
    }
    if (!cJSON_IsArray(config))
    {
        ESP_LOGE(TAG, "Invalid Custom Setup JSON - Not an array");
        return;
    }
    cJSON_ArrayForEach(J, config)
    {
        GET_S(tag, "tag");
        GET_S(level, "level");
        auto ll = str2ll(level);
        esp_log_level_set(tag, ll);
        logl = std::max(logl, ll);
    }
    esp_log_set_level_master(logl);
}

static void log_stop_ip_logger()
{
    if (!log_task_handle) return;
    if (!remote_logger_active) {vTaskDelete(log_task_handle); log_task_handle=NULL; return;}
    xTaskNotify(log_task_handle, 55, eSetValueWithOverwrite);
    for(int i=0; i<100; ++i)
    {
        vTaskDelay(100);
        if (!log_task_handle) return;
    }
    vTaskDelete(log_task_handle); 
    log_task_handle=NULL;
    remote_logger_active = false;
}

static void log_task( void * )
{
    int sock = -1;

    auto write = [&](const char* data, size_t size) {
        if (sock == -1) return;
        if (send(sock, data, size, 0) != size)
        {
            close(sock);
            sock = -1;
            remote_logger_active = false;
            printf("ERROR: RemoteLogger: Connection lost (or write error)");
        }
    };

    for(;;)
    {
        if (sock == -1)
        {
            struct sockaddr_in dest_addr;

            dest_addr.sin_addr.s_addr = global_setup.log_ip;
            dest_addr.sin_family = AF_INET;
            dest_addr.sin_port = htons(SC_LogPort);

            sock = socket(AF_INET, SOCK_STREAM, IPPROTO_IP);
            if (sock < 0) 
            {
                printf("ERROR: RemoteLogger: Unable to create socket");
                vTaskDelay(1000);
                continue;
            }

            int err = connect(sock, (struct sockaddr *)&dest_addr, sizeof(struct sockaddr_in6));
            if (err) 
            {
          	    //printf("ERROR: RemoteLogger: Socket unable to connect: errno %d", errno);
                close(sock);
                sock = -1;
                vTaskDelay(s2ticks(SC_ConnectTout));
                continue;
            }
        }
        remote_logger_active = true;
        uint32_t index = ulTaskNotifyTake(pdTRUE, ms2ticks(SC_LogTaskWKUP));
        if (index == 55)
        {
            shutdown(sock, 0);
            close(sock);
            sock = -1;
            remote_logger_active = false;
            log_task_handle = NULL;
            vTaskDelete(NULL);
            return;
        }
        {
            LOCK;
            if (log_bufs[log_buf_idx].length()==0) continue;
            log_buf_idx ^= 1;
            auto& P = log_bufs[log_buf_idx];
            data_sent += P.length();
            max_remote_buffer = std::max<uint32_t>(max_remote_buffer, P.length());
        }
        auto& P = log_bufs[log_buf_idx];
        if (P.was_spliced()) {++log_spliced; write("...\n", 4);}
        write(P.c_str(), P.length());
        if (prn_buf_size() && P.length() > prn_buf_size()) P.zap();
        else P.clear();
    }
}

static void log_start_ip_logger()
{
    if (log_task_handle) return;
    xTaskCreate(log_task, "LogSender", TSS_LogSender, NULL, TP_LogSender, &log_task_handle);
}
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

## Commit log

2023-09-09 Initial version
    [KS_6_ADI.step, ev_cal.kicad_pcb, ev_cal.kicad_sch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]
2023-09-29 Added WEB servers
    [partitions_eventcal.csv]
2023-10-15 Fixed EEPROM access Fixed WiFi code Running WEb services
    [hadrware.cpp]
2023-10-31 Small headers refactor + pin attached HW common class
2023-11-02 Debugging of Activity in progress
    [partitions_eventcal.csv]
2023-11-04 Adjust Print buffers in heap
2023-12-06 Fix for DoorOpen module
    [hadrware.cpp]
2023-12-25 Added support for DOS/UTF8 mix in UTF8 encoded strings. Added print of User name in entry messages.
2025-02-04 Added OTA support
    [partitions_eventcal.csv]
2025-02-10 Started support for local (on-device) Gift Loading
2025-02-25 Running local LCD Gift loading action - Toggle Buttons part
2025-04-26 Added PDF of schematic
    [ev_cal.kicad_sch, lcd.kicad_sch, solenoid.kicad_sch]
2025-04-27 Added CoreDump support
    [partitions_eventcal.csv]

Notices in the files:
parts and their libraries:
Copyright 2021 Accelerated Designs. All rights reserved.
